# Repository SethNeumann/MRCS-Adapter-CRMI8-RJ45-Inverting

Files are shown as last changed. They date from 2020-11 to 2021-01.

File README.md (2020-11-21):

# REPO NAME: EagleTemplate-new
## License: Creative Commons Attribution-NonCommercial-ShareAlike

The improved CMRI8-RJ45 adapter (with limiting resistor pads) AND an inverter

This version is aimed at CMRI users using common cathode signals and a logic true output.
It includes a 74HC540 octal latch inverter (but the latches are hardwared on) to source 
~ 8 mA @ 4V, which should be adequate for modern LEDs.  Other versions of 74xx540 will 
probably work as well as 74xx541 (non inverting) although I haven't tested them.

John Plocher did the original design based on a request from Jay Beckham, and later extended
it to support limiting resistors based on user requests.  Kris Puccinelli modified this 
design to include an octal inverter, but not on EAGLE.  This is an EAGLE version, designed
for panelization.

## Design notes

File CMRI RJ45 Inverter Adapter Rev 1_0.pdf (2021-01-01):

Page 1 | www.modelrailroadcontrolsystems.com | January 1, 2021

# RJ45 Inverter

Revision v1.0 January 1, 2021

Seth Neumann, seth@modelrailroadcontrolsystems.com

Introduction
This document describes the RJ45 Inverter and how to assemble and install it.

Revision History
v0.1 | December 9, 2020 SCN
V1.0 | show production panel, change of Prop 65 warning position

Page 2 | www.modelrailroadcontrolsystems.com | January 1, 2021

## Table of Contents

### 1 INTRODUCTION | 3 2 IDENTIFICATION AND INFORMATION | 4 2.1 BILL OF MATERIALS | 4 2.2 SCHEMATIC DRAWING | 5 3 THEORY OF OPERATION | 6 4 OPTIONS | 7 1.1. CONNECTORS | 7 1.2. DETAILED ASSEMBLY | 7 5 TESTING | 9 6 INSTALLATION AND CONNECTIONS | 10

## Table of Figures

FIGURE 1 - RJ45 INVERTER IN STANDARD MOLEX CONFIGURATION | 3
FIGURE 2 - SCHEMATIC | 5
FIGURE 3 - BOTTOM OF RJ 45 INVERTER BOARD - CUT TRACES UNDER THE PROP 65 WARNING | 7
FIGURE 4 – STANDARD RJ45 BREAKOUT | 9
FIGURE 5 - RJ45 INVERTER ON SMINI | 10

## Table of Tables

TABLE 1- BILL OF MATERIALS REV1.0 | 4

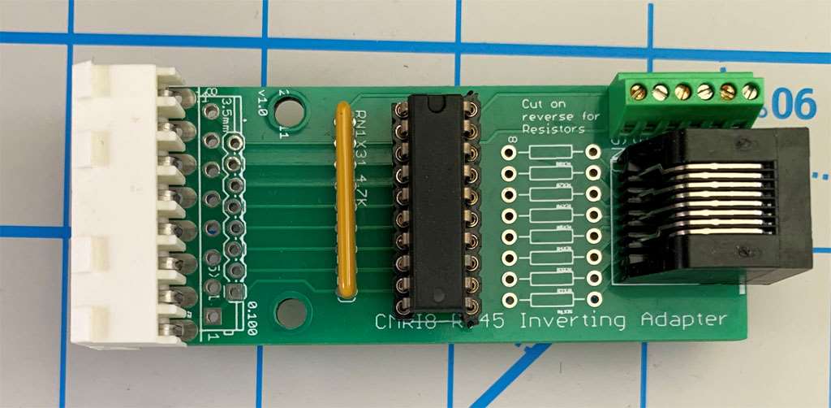
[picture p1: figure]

Page 3 | www.modelrailroadcontrolsystems.com | January 1, 2021

### 1 INTRODUCTION

Figure 1 - RJ45 Inverter in Standard Molex Configuration

This board is a variation on the CMRI (0.156 Molex) to RJ45 adapter John Plocher developed for Jay Beckham. John has since enhanced it with individual resistor pads. This version is based on a Kris Puccinelli variation which includes a 74HC540 octal inverter which can source ~ 8mA for use with common cathode signals.

- The RJ45 Inverter operates at 5 volts and draws about 3mA + 8 mA per lamp that’s on
- On board pull-ups condition the open collector outputs of an SMINI or DOUT to logic level
- 3 styles of input connector are supported:
o 0.156 8 position female Molex (I expect this to be the standard as the product is aimed at CMRI users and it mates with Dr Chubb’s standard output connector
o 3.5 mm 8 position screw terminal
o 0.100 (2.54mm) mm 8 position screw terminal or another 0.100 connector you’d like to use All components are through-hole technology for ease of assembly and repair.
- 8 resistor pads are provided for ¼ W axial resistors for current limiting the LEDs in the signal
- A 6 position 0.100 (2.54mm) terminal block is provided for +5 and ground, 2 terminals are bused for +5 to allow easy daisy chaining and 4 are bused to ground for daisy chaining and ground reference connections.
- Available Assembled and tested with your choice of connector or as a bare board, panel of 3
- If you want a variant, we don’t stock, send us an email and we’ll be happy to quote on orders of 10 or more.

Page 4 | www.modelrailroadcontrolsystems.com | January 1, 2021

### 2 IDENTIFICATION AND INFORMATION

### 2.1 BILL OF MATERIALS

Qty Value | Device | Package | Parts | Description
1 | CONNECTOR-M06LOCK 1X06_LOCK | J4 | Header 6 Standard 6-pin 0.1 header"
1 | CONNECTOR-
| M083.5MM-2* | SCREWTERMINAL-
| | 3.5MM-8 | J2 | Header 8
1 | CONNECTOR-
| M08LOCK* | 1X08_LOCK | J5 | Header 8
1 | KK-156-8F* | KK-156-8-F | J3 | KK 156 HEADER
8 | 0 RPTH04 | AXIAL-0.4-RES | R1, R2, R3, R4, R5, R6,
| | | R7, R8 | Resistor
1 4.7K | GE08RP | SIL9 | RN1 | SIL RESISTOR
1 74HC540N | 74HC540N | DIL20 | IC1 | Inverting Octal BUFFER and LINE DRIVER, 3-
| | | | state
1 20 Pin DIL Socket 20 Pin DIL Socket | 20 Pin DIL Socket | IC1 | 20 Pin DIL Socket
1 RJ45 | CONNECTOR-RJ45-
| FRONT | RJ45-NO-SHIELD | J1 | CORCOM Modular RJ Jacks No Shield
1 Circuit Board | Circuit Board | 33 x 100 | | circuit board

Table 1- Bill of Materials Rev 1.0

*Pick only the connectors you’ll be using, in most cases the KK-156-8F (Molex).

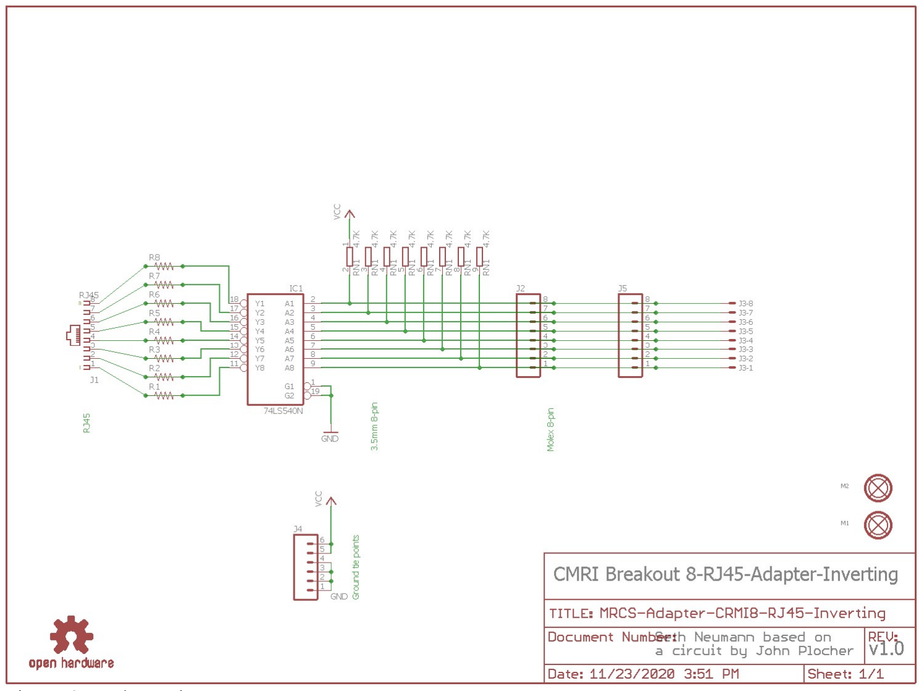
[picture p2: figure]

Page 5 | www.modelrailroadcontrolsystems.com | January 1, 2021

### 2.2 SCHEMATIC DRAWING

Figure 2 - Schematic

Page 6 | www.modelrailroadcontrolsystems.com | January 1, 2021

### 3 THEORY OF OPERATION

The 74HC540 is an inverter, that is each input (low, high) appears in the opposite state at the output. It expects a logic level input, so a 4.7Kohm pull-up is provided for the input. A 9 pin Single Inline Package (SIP) is used for ease of assembly and to save real estate.

If you want a buffered logic level output from a DOUT or SMINI you could use a 74HC541 but it might be more straightforward to simply modify the SMINI/DOUT by jumping from the output of the 74HCT537s directly to the pins intended for the collectors of the output transistors. However, this solution uses an unmodified SMINI/DOUT.

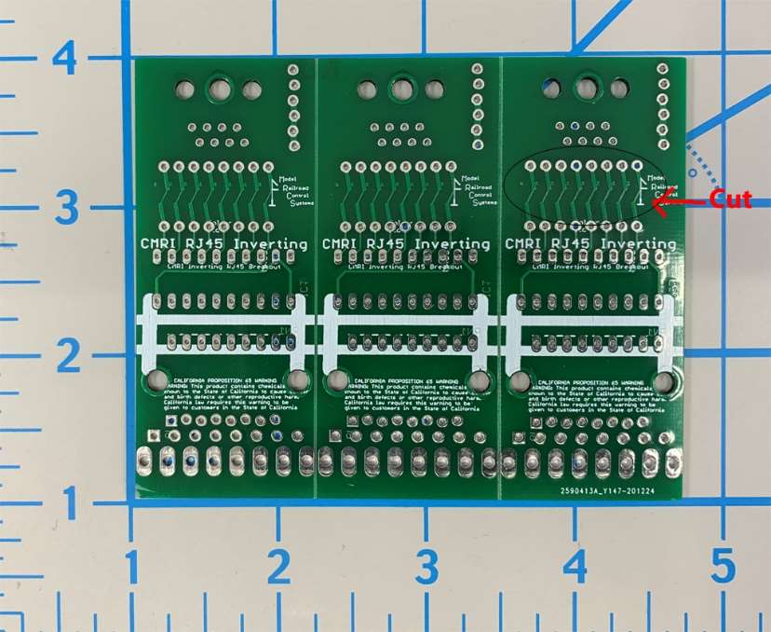
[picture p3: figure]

Page 7 | www.modelrailroadcontrolsystems.com | January 1, 2021

### 4 OPTIONS

1.1.CONNECTORS

- Choice of input connectors as indicated in the introduction above. If you are ordering an assembled and tested unit from MRCS and you would prefer a different connector, please contact us at sales@modelrailroadcontrolsystems.com and indicate your preference and we’ll provide a quotation.
- Input power and ground are on the 6 pin connector next to the modular jack.

1.2.DETAILED ASSEMBLY
[ ] All of the components are through-hole technology with wire leads. The general rule is install the lowest components first, working towards components that are higher off the board. Start by inserting the lower height components (IC Socket and SIP). This enables you to support the low components as you solder them.

[ ] Resistors
[ ] If you are inserting limiting resistors, cut the corresponding traces on the back and check with an ohmmeter that they are really open. The hole spacing is 0.400. Use a lead bender to form ¼ or 1/8 W resistors and install them as needed. You may need to use different values for different colors, especially if mixing green and red to make yellow.

Figure 3 - bottom of RJ 45 inverter board - cut traces as shown
[ ] Install SIP Resistor pack RN1 . The common pin (dark dot on the SIP) goes towards the top of.the board, following the text.

[ ] IC Socket
[ ] Install U1, notch pointing up

[ ] Connectors
[ ] Install your choice of input connector (JP1, JP2, JP3) [ ] Install power connector (JP4)

Page 8 | www.modelrailroadcontrolsystems.com | January 1, 2021

[ ] Install RJ45 output connector (J1)

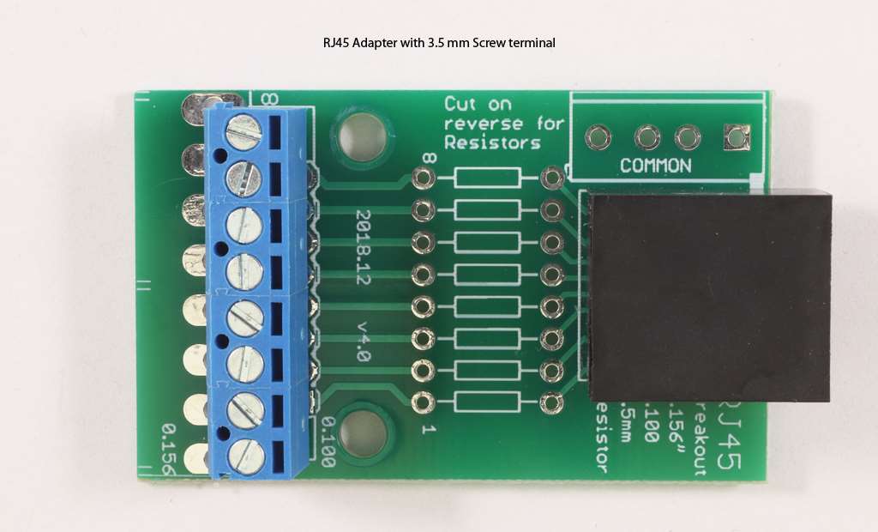
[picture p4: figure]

Page 9 | www.modelrailroadcontrolsystems.com | January 1, 2021

### 5 TESTING

Testing your RJ45 Inverter is quick and simple:
1. Apply positive voltage (5 VDC) and ground between on JP4 (note 4 terminals towards the IC are ground, and the 2 away from the IC are +.
2. Connect an LED (observe polarity) in series with a suitable limiting resistor (RED Led, 330 Ohms at 5 Volts), with the Cathode (short lead) to a spare Ground terminal. Connect the resistor to each output terminal in turn. Use a stripped end of an Ethernet cable or our standard RJ45 adapter, to get easier access to the outputs.
3. Apply a ground from a spare ground terminal to each input in turn. You should see the LEDs turn on as you ground the input.

Figure 4 – Standard RJ45 Breakout

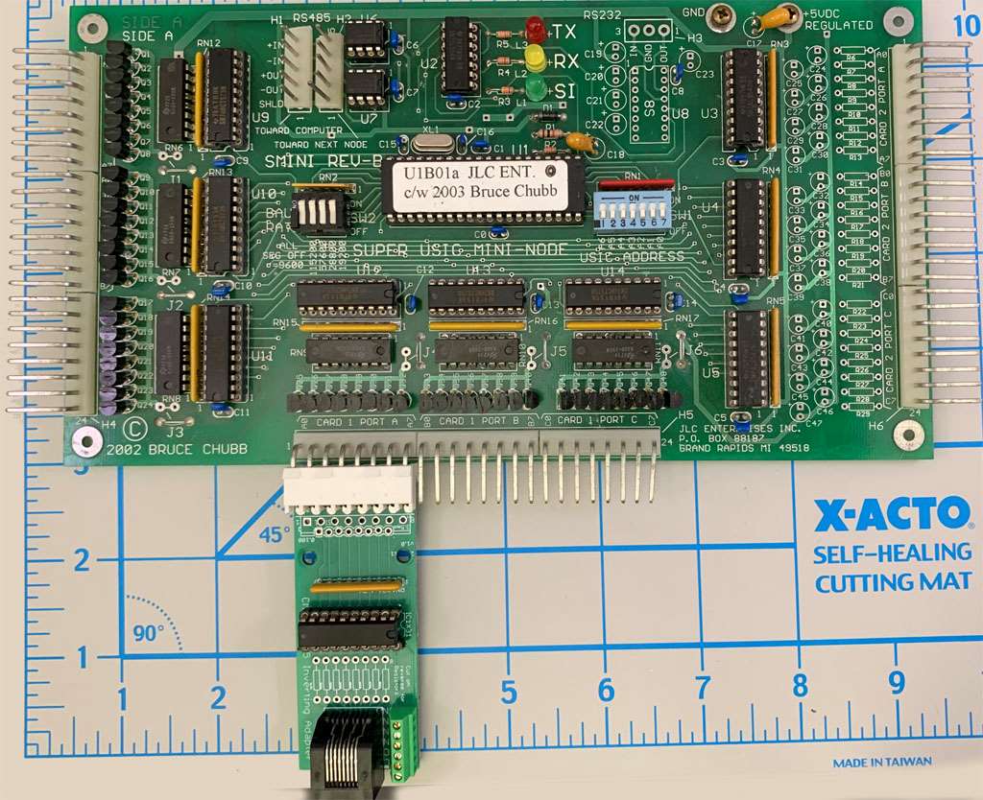
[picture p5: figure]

Page 10 | www.modelrailroadcontrolsystems.com | January 1, 2021

### 6 INSTALLATION AND CONNECTIONS

Plug the Molex on to the SMINI/DOUT, matching component sides. Screw holes are providedif you need to support the RJ45 inverter, but the Molex pins should hold them in place.

Plug an Ethernet Cable into the RJ45 and route it to whatever it’s connecting to. We offer the standard version of the RJ45 adapter (which also has resistor pads if you’d prefer to add them at the signal end).

Figure 5 - RJ45 Inverter Installed on SMINI

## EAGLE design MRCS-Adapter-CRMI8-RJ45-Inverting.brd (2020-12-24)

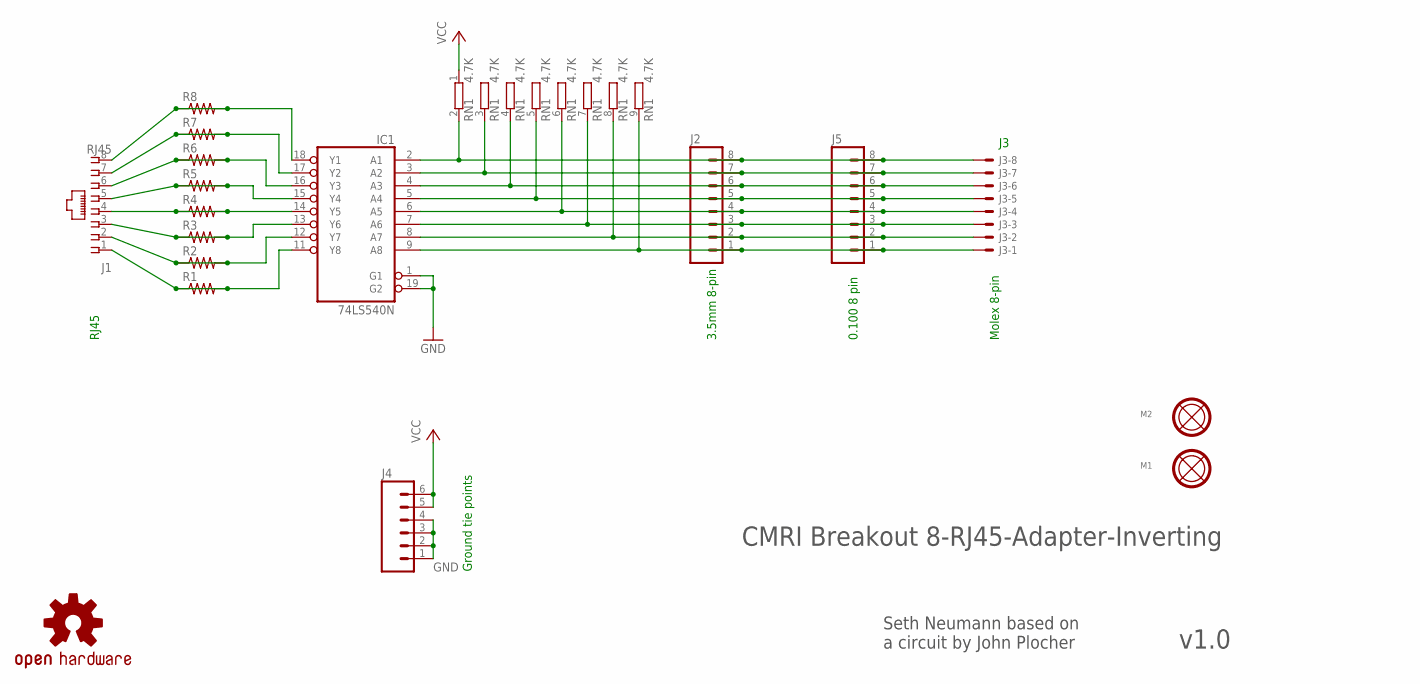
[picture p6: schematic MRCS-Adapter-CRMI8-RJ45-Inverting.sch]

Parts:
IC1: 74LS540N; DIL20
J1: RJ45; RJ45-NO-SHIELD
J2: CONNECTOR-M083.5MM-8; SCREWTERMINAL-3.5MM-8
J3: KK-156-8F; KK-156-8-F
J4: CONNECTOR-M06LOCK; 1X06_LOCK
J5: CONNECTOR-M08LOCK; 1X08_LOCK
M1, M2: MOUNTINGHOLE
R1, R2, R3, R4, R5, R6, R7, R8: RPTH04; AXIAL-0.4-RES
RN1: 4.7K; SIL9
U$1: DOC-OSHW-LOGO-L; OSHW-LOGO-L

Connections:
GND: IC1.1 (G1), IC1.10 (GND), IC1.19 (G2), J4.1, J4.2, J4.3, J4.4
L1: IC1.9 (A8), J2.1, J3.1, J5.1, RN1.9 (2)
L2: IC1.8 (A7), J2.2, J3.2, J5.2, RN1.8 (2)
L3: IC1.7 (A6), J2.3, J3.3, J5.3, RN1.7 (2)
L4: IC1.6 (A5), J2.4, J3.4, J5.4, RN1.6 (2)
L5: IC1.5 (A4), J2.5, J3.5, J5.5, RN1.5 (2)
L6: IC1.4 (A3), J2.6, J3.6, J5.6, RN1.4 (2)
L7: IC1.3 (A2), J2.7, J3.7, J5.7, RN1.3 (2)
L8: IC1.2 (A1), J2.8, J3.8, J5.8, RN1.2
unnamed: IC1.18 (Y1), J1.8, R8.P$1 (1), R8.P$2 (2)
unnamed: IC1.17 (Y2), J1.7, R7.P$1 (1), R7.P$2 (2)
unnamed: IC1.16 (Y3), J1.6, R6.P$1 (1), R6.P$2 (2)
unnamed: IC1.15 (Y4), J1.5, R5.P$1 (1), R5.P$2 (2)
unnamed: IC1.14 (Y5), J1.4, R4.P$1 (1), R4.P$2 (2)
unnamed: IC1.13 (Y6), J1.3, R3.P$1 (1), R3.P$2 (2)
unnamed: IC1.12 (Y7), J1.2, R2.P$1 (1), R2.P$2 (2)
unnamed: IC1.11 (Y8), J1.1, R1.P$1 (1), R1.P$2 (2)
VCC: IC1.20 (VCC), J4.5, J4.6, RN1.1

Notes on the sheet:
Molex 8-pin
3.5mm 8-pin
RJ45
v1.0
Ground tie points
CMRI Breakout 8-RJ45-Adapter-Inverting
Seth Neumann based on a circuit by John Plocher
0.100 8 pin

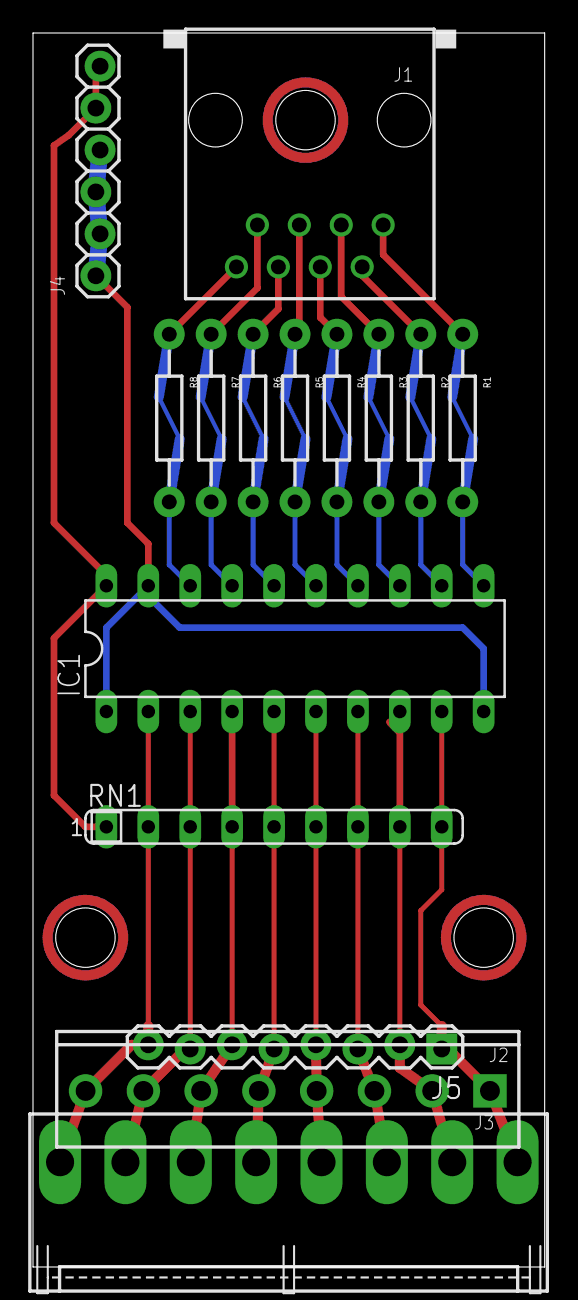
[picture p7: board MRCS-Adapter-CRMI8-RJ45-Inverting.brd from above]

Board: 2 copper layers, 31.0 x 74.8 mm, 21 parts (0 on the bottom side), 18 nets.

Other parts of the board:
M3: MOUNTINGHOLE
U$2: CA-PROP65WARNING
U$3: MRCSLOGOBTM

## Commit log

2020-11-22 upload starting copy from non-inverting design
    starting from older design
    [EagleTemplate-new.brd, MRCS-Adapter-CRMI8-RJ45-Inverting.brd, MRCS-Adapter-CRMI8-RJ45-Inverting.sch]
2020-11-22 First pass at modifying the CMRI8-RJ45 adapter
    remove the frog power, add the 74HC540 and Vcc (+5) and GND
2020-11-22 added 74LS540, modified connectors
    Added inverter (74LS540), removed frog connector, added Vcc, Gnd for logic supply
    [MRCS-Adapter-CRMI8-RJ45-Inverting.brd, MRCS-Adapter-CRMI8-RJ45-Inverting.sch]
2020-11-22 fixed ground trace
    Missing ground trace.
2020-11-23 various adjustments
    minor board layout adjustments
    [MRCS-Adapter-CRMI8-RJ45-Inverting.brd, MRCS-Adapter-CRMI8-RJ45-Inverting.sch]
2020-11-24 final changes for panelizing
    clean up to facilitate the panelizer
    [MRCS-Adapter-CRMI8-RJ45-Inverting.sch]
2020-12-03 first production version
    Inverting version of RJ45 adapter originally designed by John Plocher for Jay Beckham. Later added limiting resistors, Kris Puccinelli asked for an inverting version
2020-12-13 Documentation
    rec 0.2 review by Kris Puccinelli
    [MRCS-Adapter-CRMI8-RJ45-Inverting-Array.brd]
2020-12-13 derivative file, should not be in Git
    removed derivative file
    [MRCS-Adapter-CRMI8-RJ45-Inverting-Array.brd]
2020-12-20 label changes for legibility
    label changes for legibility
    [MRCS-Adapter-CRMI8-RJ45-Inverting.sch]
2020-12-24 Minor label changes
    the Claifornia Prop 65 warning covered the cuttable links under the limiting resistor pads, so I moved them and deleted some of John's SPCoast comments. It is important that the user can see the link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
    [MRCS-Adapter-CRMI8-RJ45-Inverting.brd]

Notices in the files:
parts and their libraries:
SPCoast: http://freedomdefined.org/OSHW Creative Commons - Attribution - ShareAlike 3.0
